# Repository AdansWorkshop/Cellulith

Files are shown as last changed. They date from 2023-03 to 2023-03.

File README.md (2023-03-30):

# Cellulith
An RP2040 based IoT/cellular device. Essentially a cell phone but very bulky.

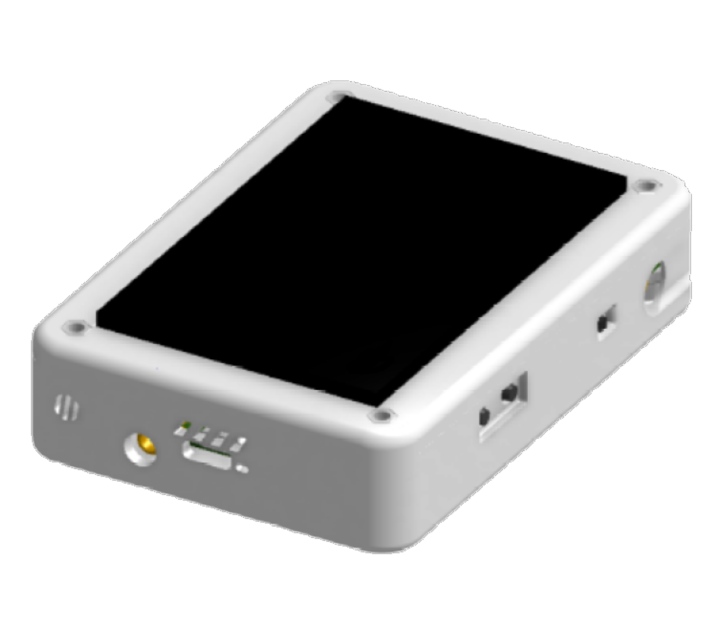
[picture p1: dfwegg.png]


# Why it's called "Cellulith"
Lith means rock or stone. For example, the Earths crust is called the lithosphere because it's a sphere of rock.

Cellu comes from cellular, like cellular phone.

The inspiration for the name was Cellulite, which was proposed by the founder of Oak Dev Tech, however I felt that the "lite" suffix made it sound small.

# Specifications
2aH Li-Po battery with USB-C charging

SIM808 GSM/GPS module with sim card socket on the bottom of the board (sim card not included)

RP2040 Cortex M0+ high-performance microcontroller running at 133MHz

8MB QSPI NOR FLASH storage

320x480 Resistive Touchscreen TFT-LCD Display

Himax HM01B0 CMOS Color Imaging Camera

Digital PWM Audio

Haptic Feedback for SMS/Voice Call notifications

# Board Dimensions
3.8" by 2.6" with M3 mounting holes in all 4 corners

# Case Dimensions
4.2" by 3" by 0.95" excluding antenna

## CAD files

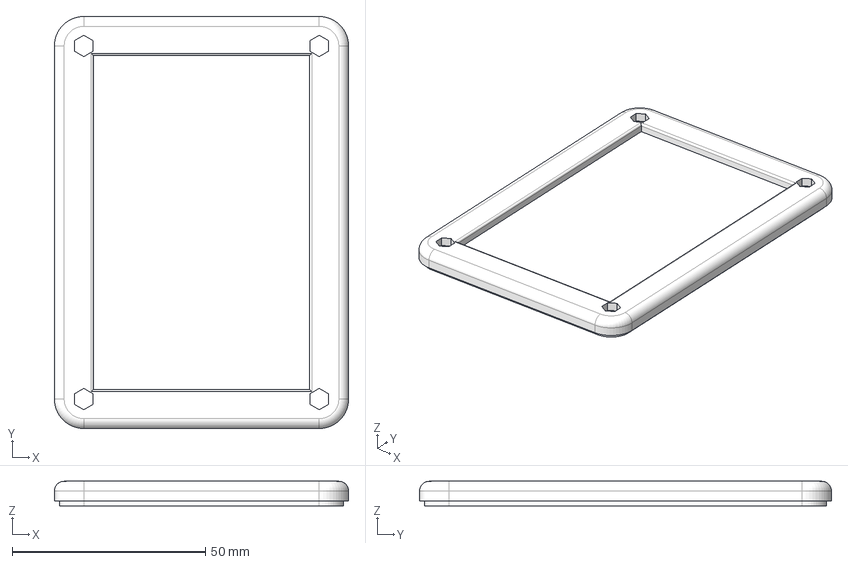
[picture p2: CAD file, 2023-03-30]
Top Case.step
76.2 x 106.7 x 6.35 mm

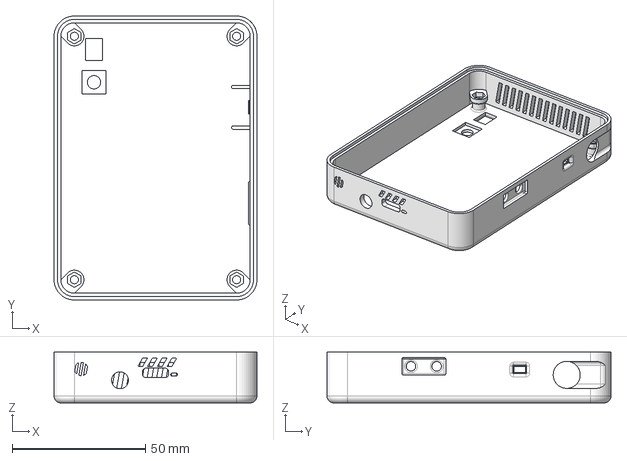
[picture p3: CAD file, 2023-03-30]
Bottom Case.step
76.2 x 106.7 x 19.1 mm

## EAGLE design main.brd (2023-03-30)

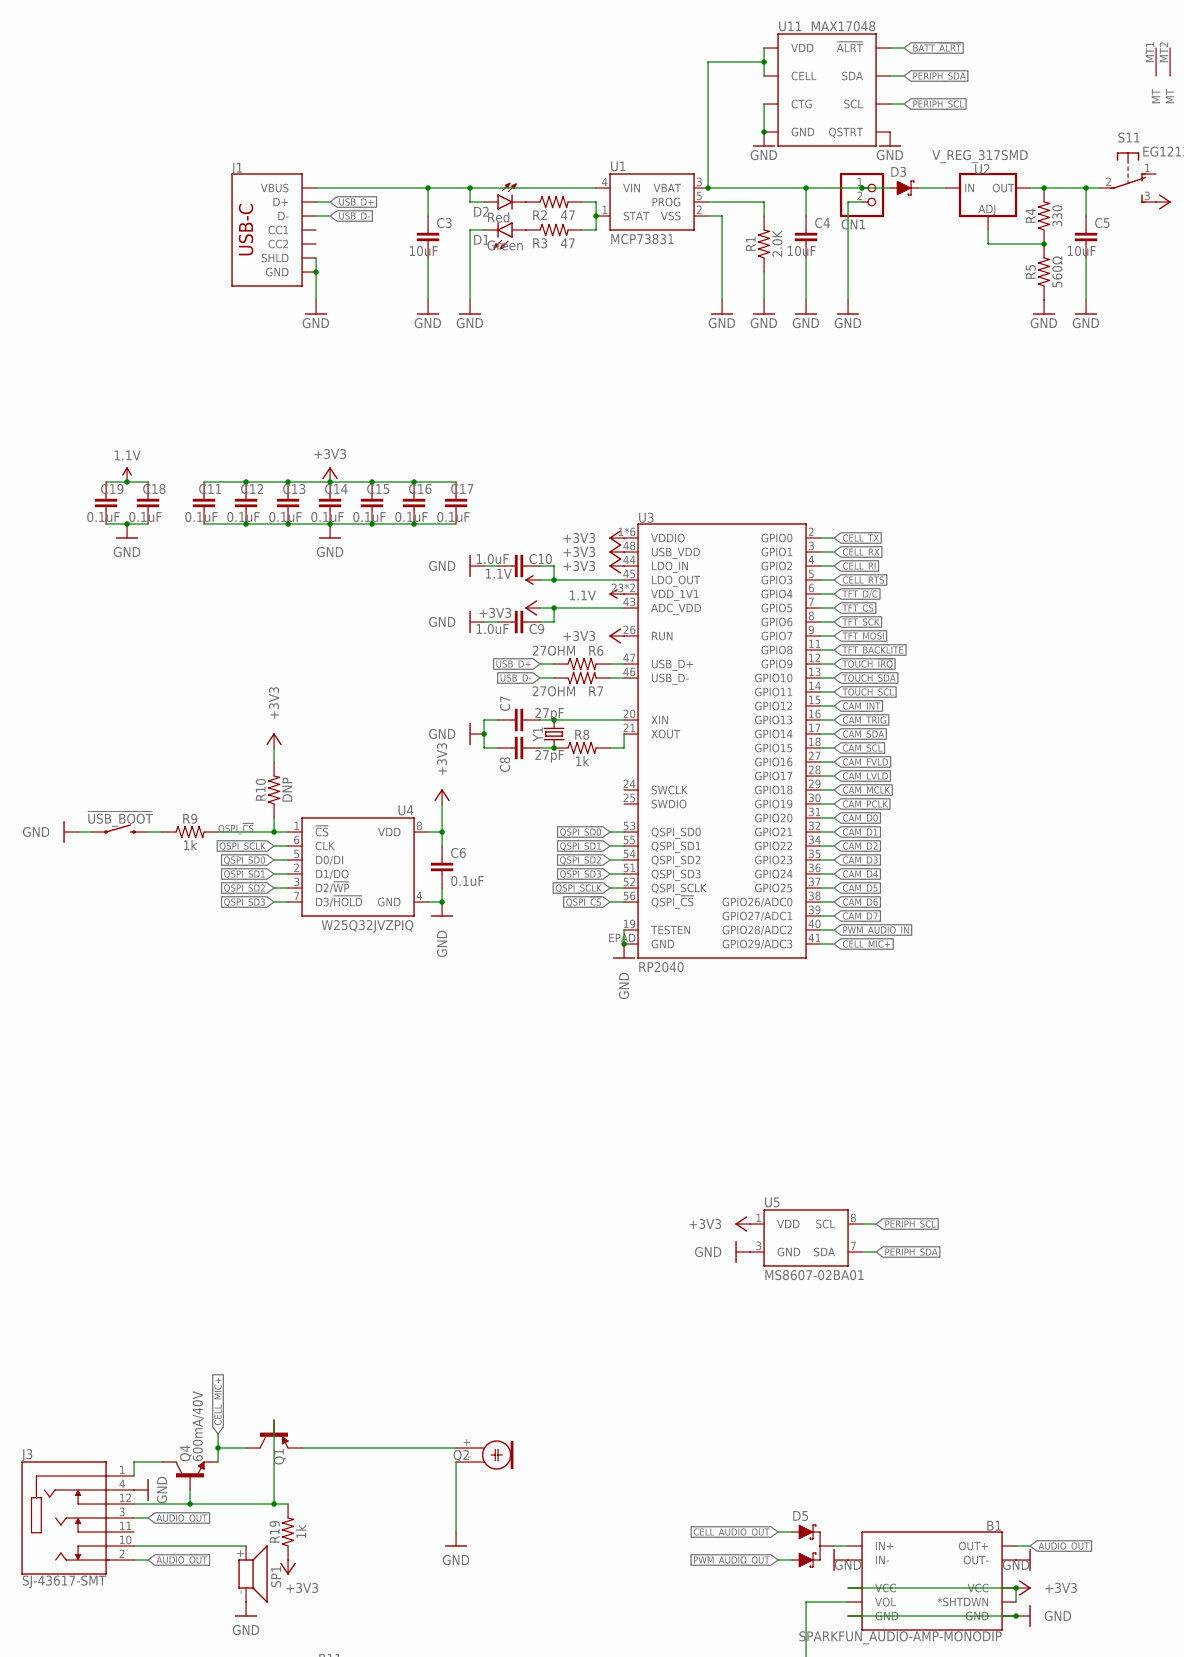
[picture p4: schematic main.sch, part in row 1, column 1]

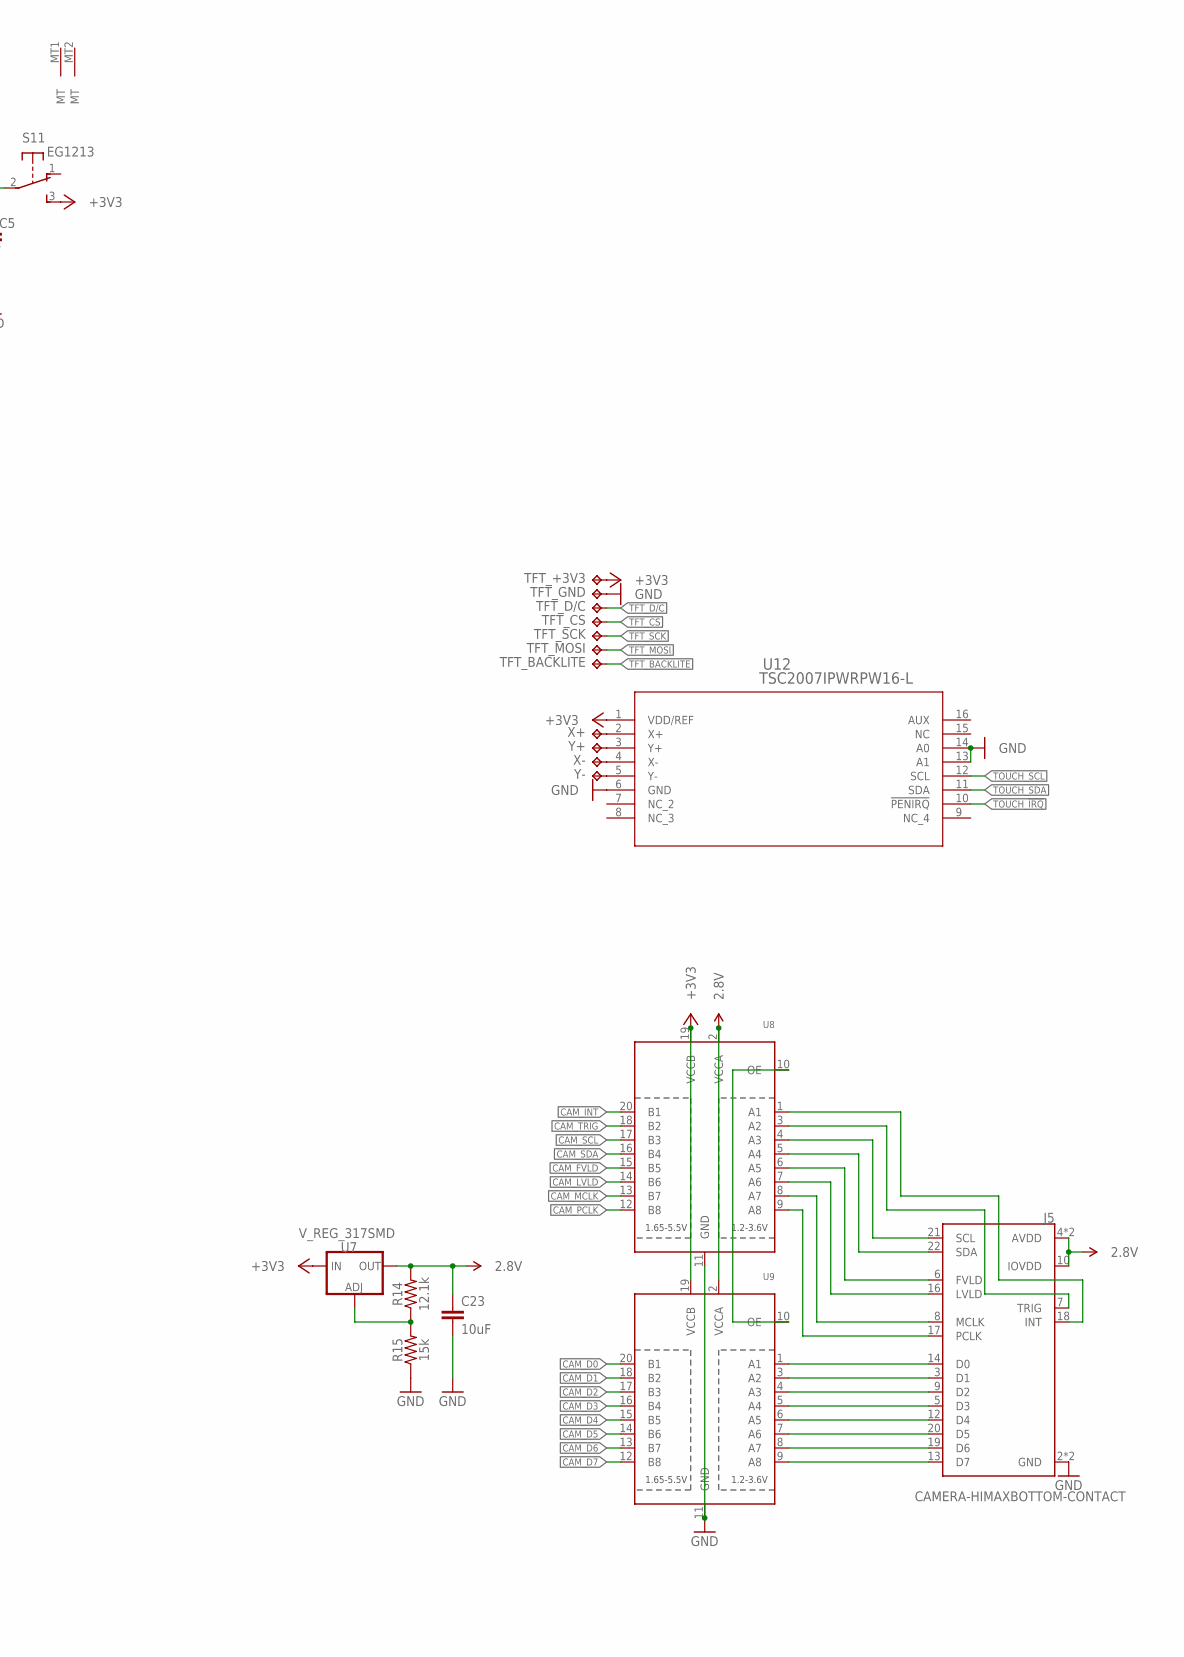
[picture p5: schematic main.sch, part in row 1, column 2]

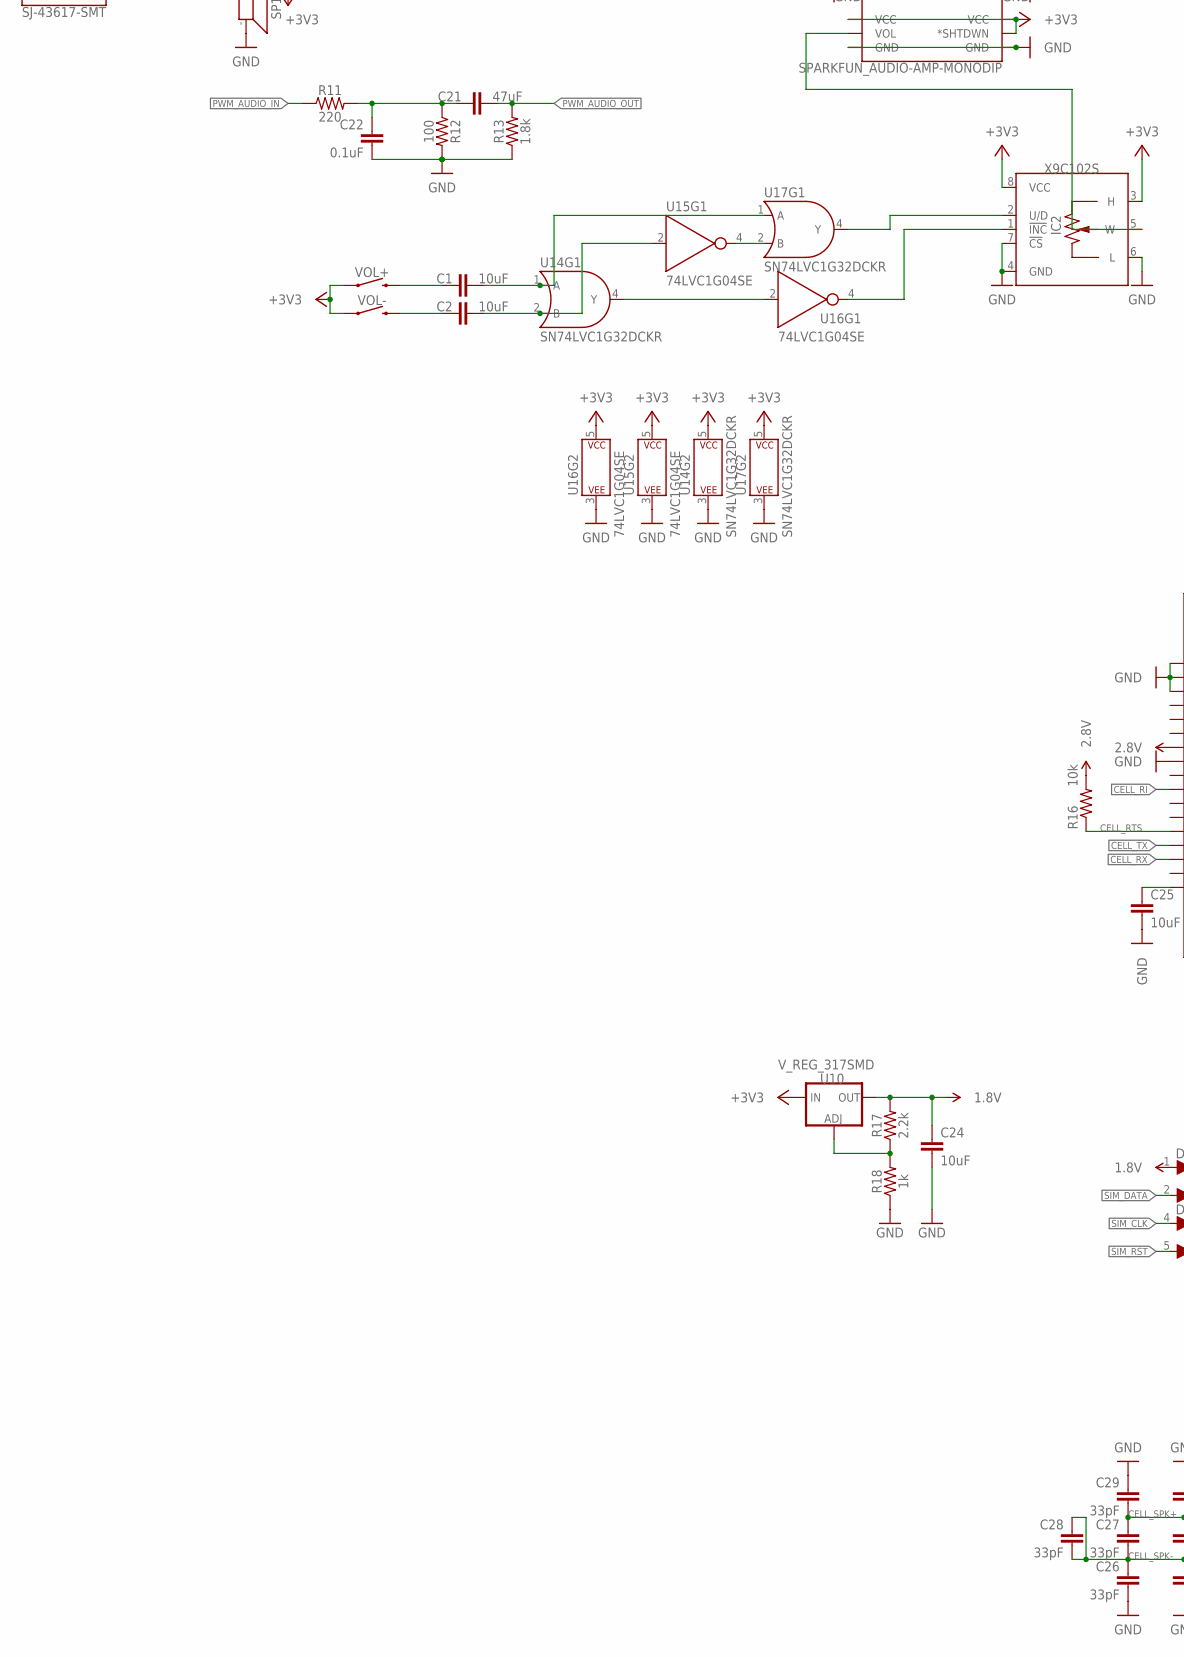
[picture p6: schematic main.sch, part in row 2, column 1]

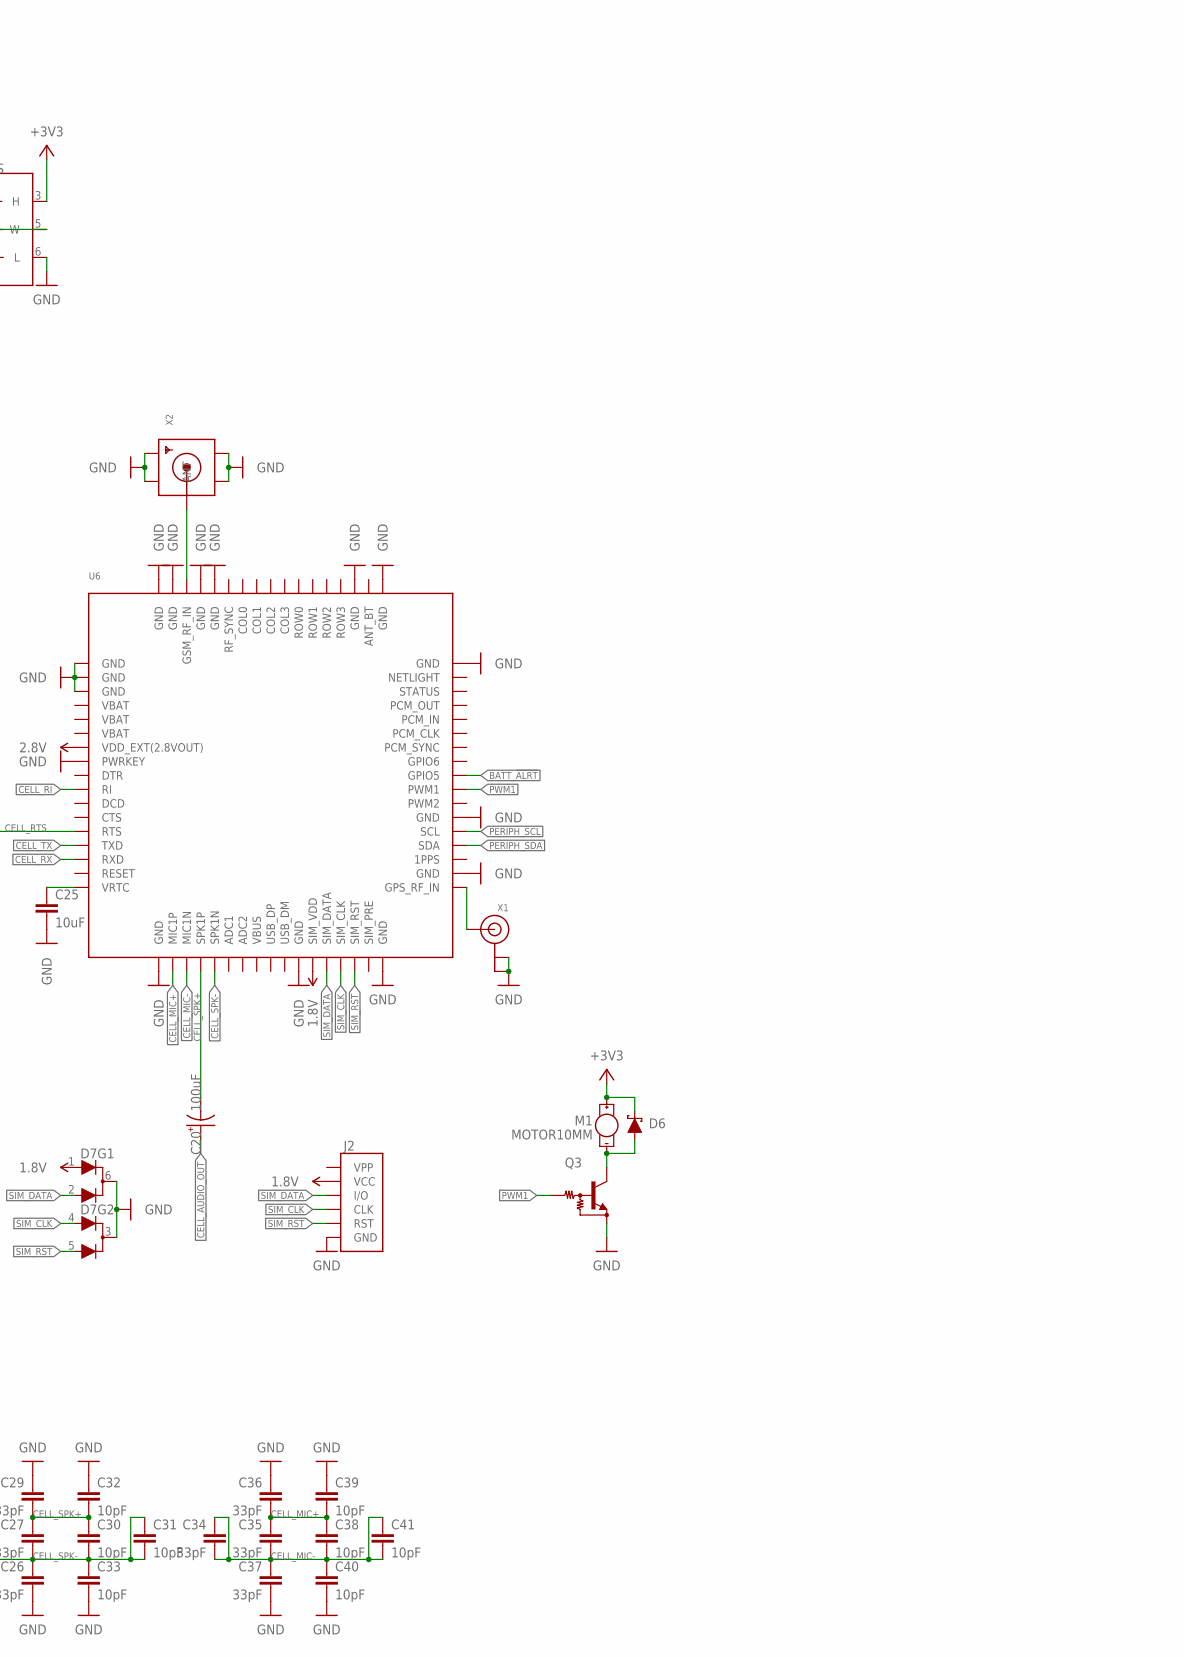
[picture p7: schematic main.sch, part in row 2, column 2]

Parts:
!USB_BOOT: MOMENTARY-SWITCH-SPST-SMD-6.0X3.5MM; TACTILE_SWITCH_SMD_6.0X3.5MM
B1: SPARKFUN_AUDIO-AMP-MONODIP; AUDIO-AMP-MONO
C1, C2, C3, C4, C5, C24: 10uF; 0402-TIGHT
C6, C11, C12, C13, C14, C15, C16, C17, C18, C19, C22: 0.1uF; 0402-TIGHT
C7, C8: 27pF; 0402-TIGHT
C9, C10: 1.0uF; 0402-TIGHT
C20: 100uF; 1206-POLAR
C21: 47uF; 0402-TIGHT
C23, C25: 10uF; 0603
C26, C27, C28, C29, C34, C35, C36, C37: 33pF; 0603
C30, C31, C32, C33, C38, C39, C40, C41: 10pF; 0603
CN1: JST_2PIN-SMT-RA; JST-PH-2-SMT-RA
D1: Green; LED-0603
D2: Red; LED-0603
D3: 3A/10V/280mV; SOD-323
D5: BAS70-05; SOT23-3
D6: 120mA/40V/370mV; SOD-523
D7: BAV70S,115; SOT363
IC2: X9C102S; SOIC08
J1: USB_C_2-LAYER_PADS; USB-C-16P-2LAYER-PADS
J2: SIMHOLDER-SIM; SIMHOLDER
J3: SJ-43617-SMT; CUI_SJ-43617-SMT
J5: CAMERA-HIMAXBOTTOM-CONTACT; FPC-24-AMPHENOL-SFV24R-1STE1HLF
M1: MOTOR10MM; VIBE-MOTOR-10MM
Q1, Q4: 600mA/40V; SOT23-3
Q2: ELECTRET; 9.7ELECTRET
Q3: TRANSISTOR-NPN_MUN2211; TRANSISTOR-NPN_SC59-BEC
R1: 2.0K; 0402-TIGHT
R2, R3: 47; 0402-TIGHT
R4: 330; 0402-TIGHT
R5: 560Ω; 0402-TIGHT
R6, R7: 27OHM; 0402-TIGHT
R8, R9, R18, R19: 1k; 0402-TIGHT
R10: DNP; 0402-TIGHT
R11: 220; 0402-TIGHT
R12: 100; 0402-TIGHT
R13: 1.8k; 0603
R14: 12.1k; 0603
R15: 15k; 0603
R16: 10k; 0402-TIGHT
R17: 2.2k; 0402-TIGHT
S1: EG1213
SP1: SMS-1308MS-2-R
TFT_+3V3: TPTP10R; TP10R
TFT_BACKLITE: TPTP10R; TP10R
TFT_CS: TPTP10R; TP10R
TFT_D/C: TPTP10R; TP10R
TFT_GND: TPTP10R; TP10R
TFT_MOSI: TPTP10R; TP10R
TFT_SCK: TPTP10R; TP10R
U1: MCP73831; SOT23-5
U2, U7, U10: V_REG_317SMD; SOT223
U3: RP2040; QFN-56
U4: W25Q32JVZPIQ; WSON-8-6X5
U5: MS8607-02BA01
U6: GSM_SIM808_LITERAL; SIM900_SMT
U8, U9: TXB0108PWR; TSSOP20
U11: MAX17048; DFN-8
U12: TSC2007IPWRPW16-L; PW16-L
U14, U17: SN74LVC1G32DCKR; SOT353
U15, U16: 74LVC1G04SE; SOT353
VOL+: MOMENTARY-SWITCH-SPST-PTH-RIGHT-ANGLE-8-020; TACTILE_SWITCH_PTH_RA_8-020
VOL-: MOMENTARY-SWITCH-SPST-PTH-RIGHT-ANGLE-8-020; TACTILE_SWITCH_PTH_RA_8-020
X1: ANTENNA_U.FL; U.FL
X2: SMACONNECTOR_EDGE; SMA_EDGELAUNCH
X+: TPTP10R; TP10R
X-: TPTP10R; TP10R
Y1: CRYSTAL-12MHZ; CRYSTAL-SMD-2X2.5MM
Y+: TPTP10R; TP10R
Y-: TPTP10R; TP10R

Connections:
1.1V: C10.1, C18.1, C19.1, U3.23 (VDD_1V1), U3.45 (LDO_OUT), U3.50 (VDD_1V1)
1.8V: C24.1, D7.1 (A1), J2.C1 (VCC), R17.2, U6.P$29 (SIM_VDD), U10.2 (OUT)
2.8V: C23.1, J5.4 (AVDD), J5.10 (IOVDD), J5.11 (AVDD), R14.2, R16.2, U6.P$7 (VDD_EXT(2.8VOUT)), U7.2 (OUT), U8.2 (VCCA), U9.2 (VCCA)
+3V3: B1.PWR+ (VCC), B1.S (*SHTDWN), B1.VOL+ (VCC), C6.1, C9.1, C11.1, C12.1, C13.1, C14.1, C15.1, C16.1, C17.1, D6.C, IC2.3 (H), IC2.8 (VCC), M1.+, R10.2, R19.1, S1.3 (S), TFT_+3V3.TP, U3.1 (VDDIO), U3.10 (VDDIO), U3.22 (VDDIO), U3.26 (RUN), U3.33 (VDDIO), U3.42 (VDDIO), U3.43 (ADC_VDD), U3.44 (LDO_IN), U3.48 (USB_VDD), U3.49 (VDDIO), U4.8 (VDD), U5.1 (VDD), U7.3 (IN), U8.19 (VCCB), U9.19 (VCCB), U10.3 (IN), U12.1 (VDD/REF), U14.5 (P$V+), U15.5 (P$V+), U16.5 (P$V+), U17.5 (P$V+), VOL+.1, VOL-.1
AUDIO_OUT: B1.OUT+, J3.2, J3.3
BATT_!ALRT: U6.P$43 (GPIO5), U11.5 (!ALRT)
CAM_D0: U3.31 (GPIO20), U9.20 (B1)
CAM_D1: U3.32 (GPIO21), U9.18 (B2)
CAM_D2: U3.34 (GPIO22), U9.17 (B3)
CAM_D3: U3.35 (GPIO23), U9.16 (B4)
CAM_D4: U3.36 (GPIO24), U9.15 (B5)
CAM_D5: U3.37 (GPIO25), U9.14 (B6)
CAM_D6: U3.38 (GPIO26/ADC0), U9.13 (B7)
CAM_D7: U3.39 (GPIO27/ADC1), U9.12 (B8)
CAM_FVLD: U3.27 (GPIO16), U8.15 (B5)
CAM_INT: U3.15 (GPIO12), U8.20 (B1)
CAM_LVLD: U3.28 (GPIO17), U8.14 (B6)
CAM_MCLK: U3.29 (GPIO18), U8.13 (B7)
CAM_PCLK: U3.30 (GPIO19), U8.12 (B8)
CAM_SCL: U3.18 (GPIO15), U8.17 (B3)
CAM_SDA: U3.17 (GPIO14), U8.16 (B4)
CAM_TRIG: U3.16 (GPIO13), U8.18 (B2)
CELL_AUDIO_OUT: C20.1 (+), D5.1 (A)
CELL_MIC+: C35.1, C36.2, C38.1, C39.2, Q1.3 (C), Q4.2 (E), U3.41 (GPIO29/ADC3), U6.P$19 (MIC1P)
CELL_MIC-: C34.1, C34.2, C35.2, C37.1, C38.2, C40.1, C41.1, C41.2, U6.P$20 (MIC1N)
CELL_RI: U3.4 (GPIO2), U6.P$10 (RI)
CELL_RTS: R16.1, U3.5 (GPIO3), U6.P$13 (RTS)
CELL_RX: U3.3 (GPIO1), U6.P$15 (RXD)
CELL_SPK+: C20.2 (-), C27.1, C29.2, C30.1, C32.2, U6.P$21 (SPK1P)
CELL_SPK-: C26.1, C27.2, C28.1, C28.2, C30.2, C31.1, C31.2, C33.1, U6.P$22 (SPK1N)
CELL_TX: U3.2 (GPIO0), U6.P$14 (TXD)
GND: !USB_BOOT.1, B1.IN-, B1.OUT-, B1.PWR- (GND), B1.VOL- (GND), C3.2, C4.2, C5.2, C6.2, C7.1, C8.1, C9.2, C10.2, C11.2, C12.2, C13.2, C14.2, C15.2, C16.2, C17.2, C18.2, C19.2, C22.2, C23.2, C24.2, C25.2, C26.2, C29.1, C32.1, C33.2, C36.1, C37.2, C39.1, C40.2, CN1.2 (1), D1.C, D7.3 (C), D7.6 (C), IC2.4 (GND), IC2.6 (L), IC2.7 (!CS), J1.GND, J1.GND2 (GND), J1.SHLD1 (SHLD), J1.SHLD2 (SHLD), J1.SHLD3 (SHLD), J1.SHLD4 (SHLD), J2.C5 (GND), J3.4, J5.2 (GND), J5.15 (GND), Q2.- (1), Q3.E, R1.1, R5.1, R12.2, R13.1, R15.1, R18.1, SP1.- (2), TFT_GND.TP, U1.2 (VSS), U3.19 (TESTEN), U3.EPAD (GND), U4.4 (GND), U5.3 (GND), U6.P$1 (GND), U6.P$2 (GND), U6.P$3 (GND), U6.P$8 (PWRKEY), U6.P$18 (GND), U6.P$28 (GND), U6.P$34 (GND), U6.P$36 (GND), U6.P$40 (GND), U6.P$51 (GND), U6.P$52 (GND), U6.P$54 (GND), U6.P$64 (GND), U6.P$65 (GND), U6.P$67 (GND), U6.P$68 (GND), U8.11 (GND), U9.11 (GND), U11.1 (CTG), U11.4 (GND), U11.6 (QSTRT), U11.9 (GND), U12.6 (GND), U12.13 (A1), U12.14 (A0), U14.3 (P$V-), U15.3 (P$V-), U16.3 (P$V-), U17.3 (P$V-), X1.1 (GND), X1.2 (GND), X2.GND@1 (GND4), X2.GND@2 (GND3), X2.GND@3 (GND2), X2.GND@4 (GND1)
unnamed: C5.1, R4.2, S1.2, U2.2 (OUT)
unnamed: C1.2, U14.1 (A), U17.1 (A)
unnamed: C2.2, U14.2 (B), U15.2 (A)
unnamed: C3.1, D2.A, J1.VBUS1 (VBUS), J1.VBUS2 (VBUS), U1.4 (VIN)
unnamed: R2.2, R3.2, U1.1 (STAT)
unnamed: D2.C, R2.1
unnamed: D1.A, R3.1
unnamed: R1.2, U1.5 (PROG)
unnamed: U15.4 (Y), U17.2 (B)
unnamed: D3.C, U2.3 (IN)
unnamed: R4.1, R5.2, U2.1 (ADJ)
unnamed: C1.1, VOL+.2
unnamed: U14.4 (Y), U16.2 (A)
unnamed: R6.2, U3.47 (USB_D+)
unnamed: R7.2, U3.46 (USB_D-)
unnamed: R8.2, U3.21 (XOUT)
unnamed: C7.2, U3.20 (XIN), Y1.P3 (2)
unnamed: C8.2, R8.1, Y1.P1 (1)
unnamed: !USB_BOOT.2, R9.1
unnamed: J5.14 (D0), U9.1 (A1)
unnamed: J5.3 (D1), U9.3 (A2)
unnamed: J3.10, SP1.+ (1)
unnamed: C21.1, C22.1, R11.2, R12.1
unnamed: B1.IN+, D5.3 (C)
unnamed: R14.1, R15.2, U7.1 (ADJ)
unnamed: J5.9 (D2), U9.4 (A3)
unnamed: U8.10 (OE), U9.10 (OE)
unnamed: J5.5 (D3), U9.5 (A4)
unnamed: J5.20 (D5), U9.7 (A6)
unnamed: J5.12 (D4), U9.6 (A5)
unnamed: J5.19 (D6), U9.8 (A7)
unnamed: J5.13 (D7), U9.9 (A8)
unnamed: J5.17 (PCLK), U8.9 (A8)
unnamed: J5.8 (MCLK), U8.8 (A7)
unnamed: J5.16 (LVLD), U8.7 (A6)
unnamed: J5.6 (FVLD), U8.6 (A5)
unnamed: J5.22 (SDA), U8.5 (A4)
unnamed: J5.21 (SCL), U8.4 (A3)
unnamed: J5.7 (TRIG), U8.3 (A2)
unnamed: J5.18 (INT), U8.1 (A1)
unnamed: U6.P$35 (GPS_RF_IN), X1.3 (SIGNAL)
unnamed: D6.A, M1.-, Q3.C
unnamed: C4.1, CN1.1 (2), D3.A, U1.3 (VBAT), U11.2 (CELL), U11.3 (VDD)
unnamed: IC2.2 (U/D), U17.4 (Y)
unnamed: U6.P$66 (GSM_RF_IN), X2.P (ANT)
unnamed: R17.1, R18.2, U10.1 (ADJ)
unnamed: C25.1, U6.P$17 (VRTC)
unnamed: Q1.2 (E), Q2.+ (2)
unnamed: IC2.1 (!INC), U16.4 (Y)
unnamed: C2.1, VOL-.2
unnamed: B1.VOL, IC2.5 (W)
unnamed: U12.2 (X+), X+.TP
unnamed: U12.3 (Y+), Y+.TP
unnamed: U12.4 (X-), X-.TP
unnamed: U12.5 (Y-), Y-.TP
unnamed: J3.12, Q1.1 (B), Q4.1 (B), R19.2
unnamed: J3.1, Q4.3 (C)
PERIPH_SCL: U5.8 (SCL), U6.P$39 (SCL), U11.7 (SCL)
PERIPH_SDA: U5.7 (SDA), U6.P$38 (SDA), U11.8 (SDA)
PWM1: Q3.B, U6.P$42 (PWM1)
PWM_AUDIO_IN: R11.1, U3.40 (GPIO28/ADC2)
PWM_AUDIO_OUT: C21.2, D5.2 (A1), R13.2
QSPI_!CS: R9.2, R10.1, U3.56 (QSPI_!CS!), U4.1 (!CS!)
QSPI_SCLK: U3.52 (QSPI_SCLK), U4.6 (CLK)
QSPI_SD0: U3.53 (QSPI_SD0), U4.5 (D0/DI)
QSPI_SD1: U3.55 (QSPI_SD1), U4.2 (D1/DO)
QSPI_SD2: U3.54 (QSPI_SD2), U4.3 (D2/!WP!)
QSPI_SD3: U3.51 (QSPI_SD3), U4.7 (D3/!HOLD!)
SIM_CLK: D7.4 (A1), J2.C3 (CLK), U6.P$31 (SIM_CLK)
SIM_DATA: D7.2 (A2), J2.C7 (I/O), U6.P$30 (SIM_DATA)
SIM_RST: D7.5 (A2), J2.C2 (RST), U6.P$32 (SIM_RST)
TFT_BACKLITE: TFT_BACKLITE.TP, U3.11 (GPIO8)
TFT_CS: TFT_CS.TP, U3.7 (GPIO5)
TFT_D/C: TFT_D/C.TP, U3.6 (GPIO4)
TFT_MOSI: TFT_MOSI.TP, U3.9 (GPIO7)
TFT_SCK: TFT_SCK.TP, U3.8 (GPIO6)
TOUCH_!IRQ: U3.12 (GPIO9), U12.10 (!PENIRQ)
TOUCH_SCL: U3.14 (GPIO11), U12.12 (SCL)
TOUCH_SDA: U3.13 (GPIO10), U12.11 (SDA)
USB_D+: J1.A6 (D+), J1.B6 (D+), R6.1
USB_D-: J1.A7 (D-), J1.B7 (D-), R7.1
VBAT: U6.P$4 (VBAT), U6.P$5 (VBAT), U6.P$6 (VBAT)
VBUS: U6.P$25 (VBUS)

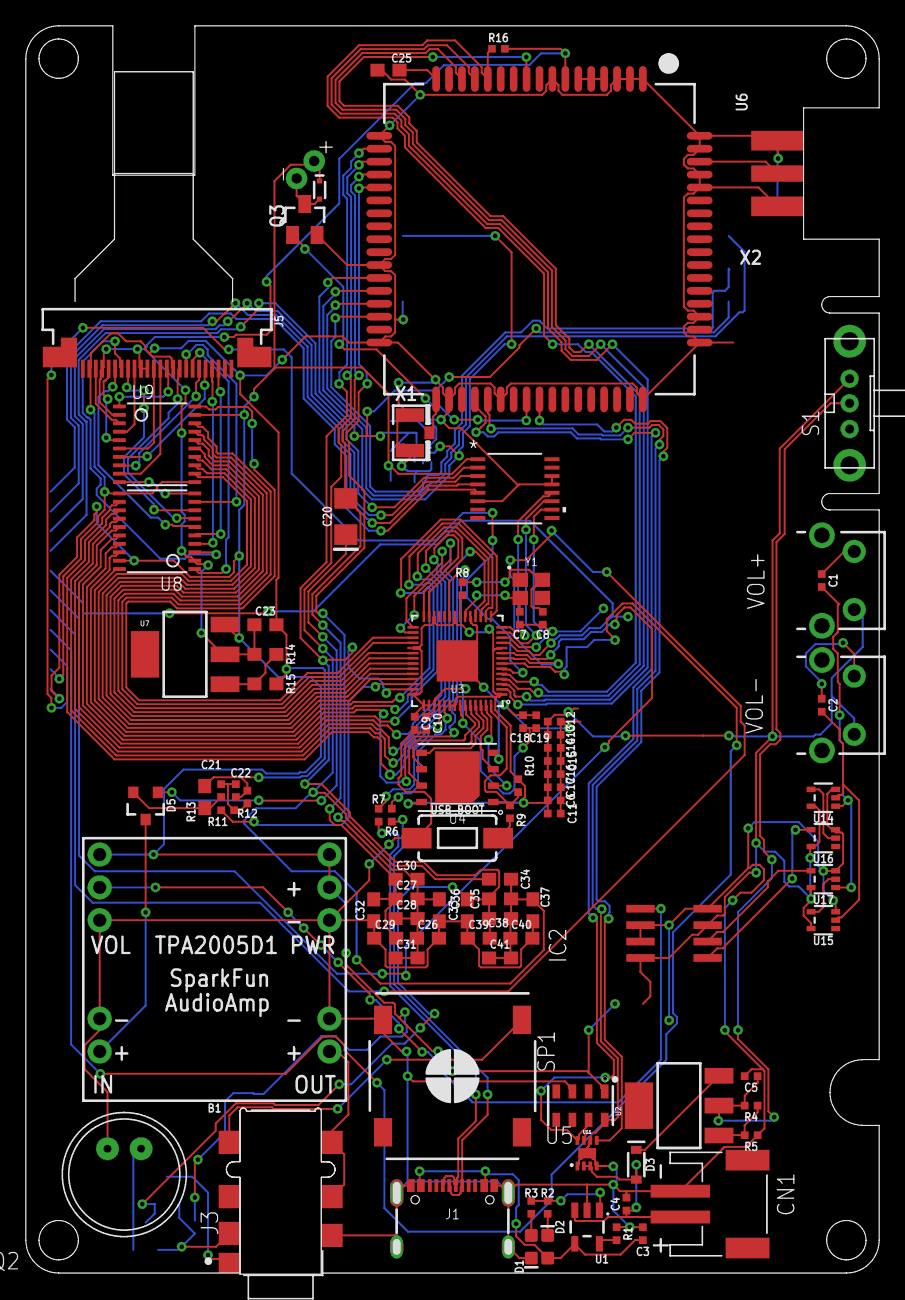
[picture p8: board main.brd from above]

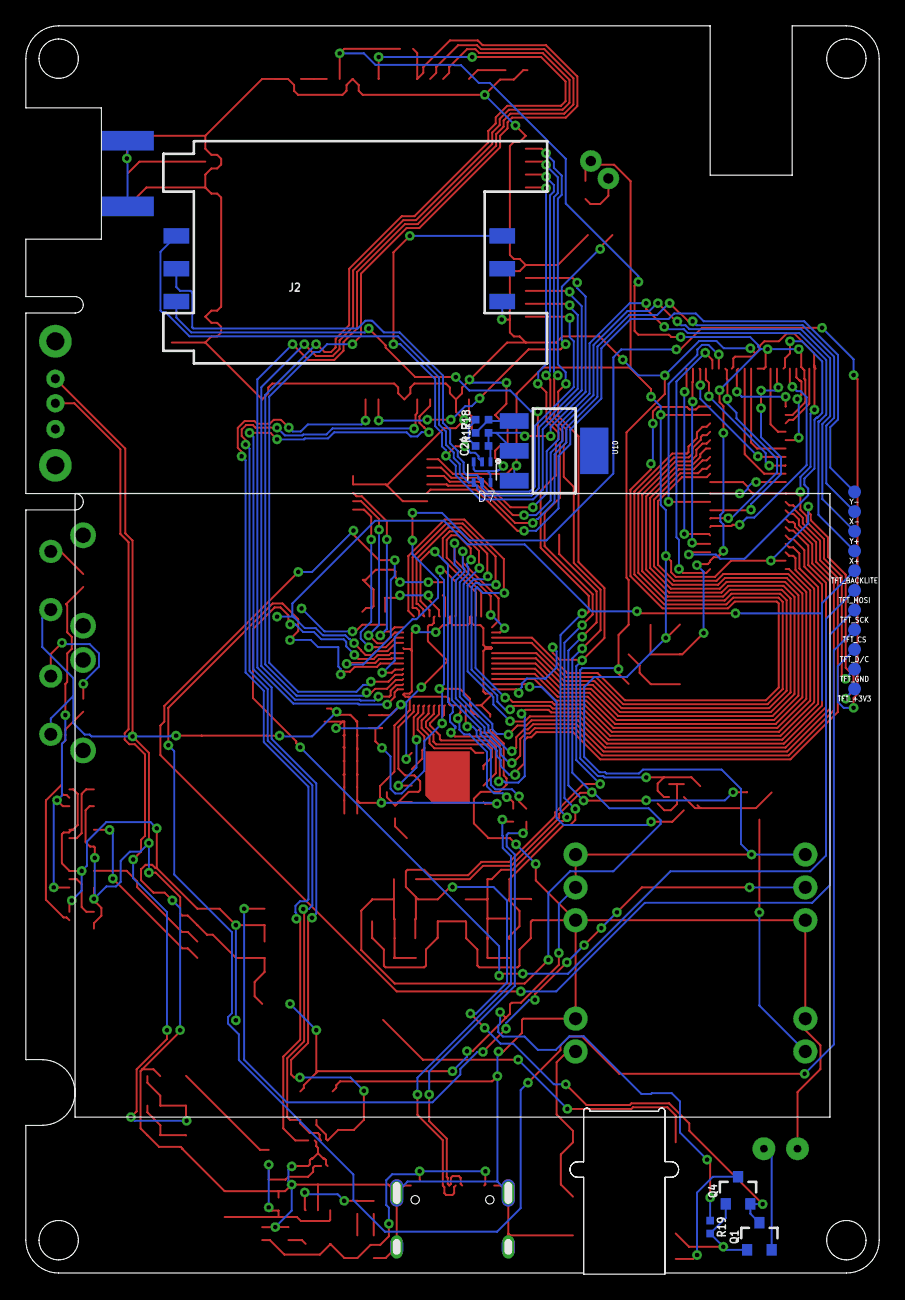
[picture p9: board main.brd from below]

Board: 2 copper layers, 66.0 x 96.6 mm, 113 parts (20 on the bottom side), 114 nets.

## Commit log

2023-03-30 EAGLE project files
    [main.brd, main.sch]
2023-03-30 Case STEP files
    [Part Studio 1 - Part 1 (3).step, Part Studio 4 - Part 1.step]
2023-03-30 Organized schematic
    [main.sch]
2023-03-30 Added Case STEP files
    [Bottom Case.step, Top Case.step]

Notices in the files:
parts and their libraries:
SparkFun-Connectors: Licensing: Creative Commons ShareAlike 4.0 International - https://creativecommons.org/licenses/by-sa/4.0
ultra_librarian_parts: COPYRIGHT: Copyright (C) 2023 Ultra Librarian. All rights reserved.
